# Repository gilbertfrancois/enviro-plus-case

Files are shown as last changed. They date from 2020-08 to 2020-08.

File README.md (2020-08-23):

# Enviro+ and PMS5003 case

## About

*Designed for environmental monitoring, Enviro+ for Raspberry Pi lets you measure air quality (pollutant gases and particulates), temperature, pressure, humidity, light, and noise level. When combined with a particulate matter sensor, it's great for monitoring air quality just outside your house (more information below), or without the particulate sensor you can use it to monitor indoor conditions.*[1]

- BME280 temperature, pressure, humidity sensor ([datasheet](https://ae-bst.resource.bosch.com/media/_tech/media/datasheets/BST-BME280-DS002.pdf))
- LTR-559 light and proximity sensor ([datasheet](references/ltr-559als-01_ds_v1.pdf))
- MICS6814 analog gas sensor ([datasheet](references/1143_Datasheet-MiCS-6814-rev-8.pdf))
- ADS1015 analog to digital converter (ADC) ([datasheet](references/ads1015.pdf))
- MEMS microphone ([datasheet](references/SPH0645LM4H-B.pdf))
- 0.96" colour LCD (160x80)
- PMS5003 particulate matter sensor

The sensors on the Enviro+ are very sensitive. The default design, where the sensor board is placed directly above the Raspberry Pi (Zero) is not great. The heat coming from the CPU of the RPi has a big influence on the BME280 temperature sensor. To overcome this, I designed a frame for mounting the Raspberry Pi Zero, the Enviro+ and the PMS5003, where the GPIO pins are connected with a ribbon cable.

| CAD | Photo |
| --- | --- |
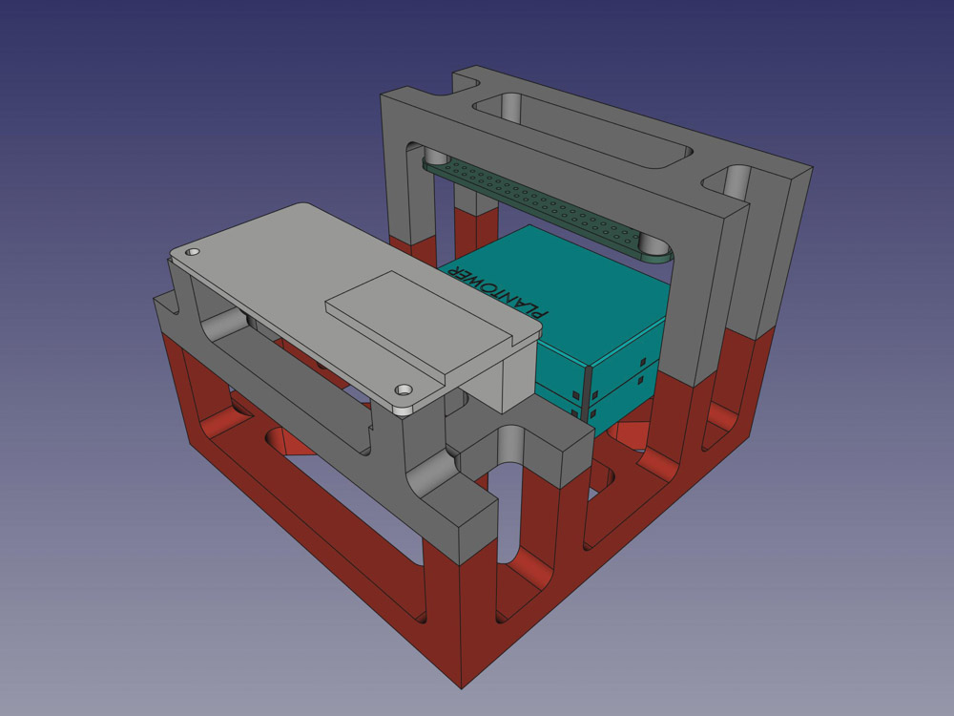
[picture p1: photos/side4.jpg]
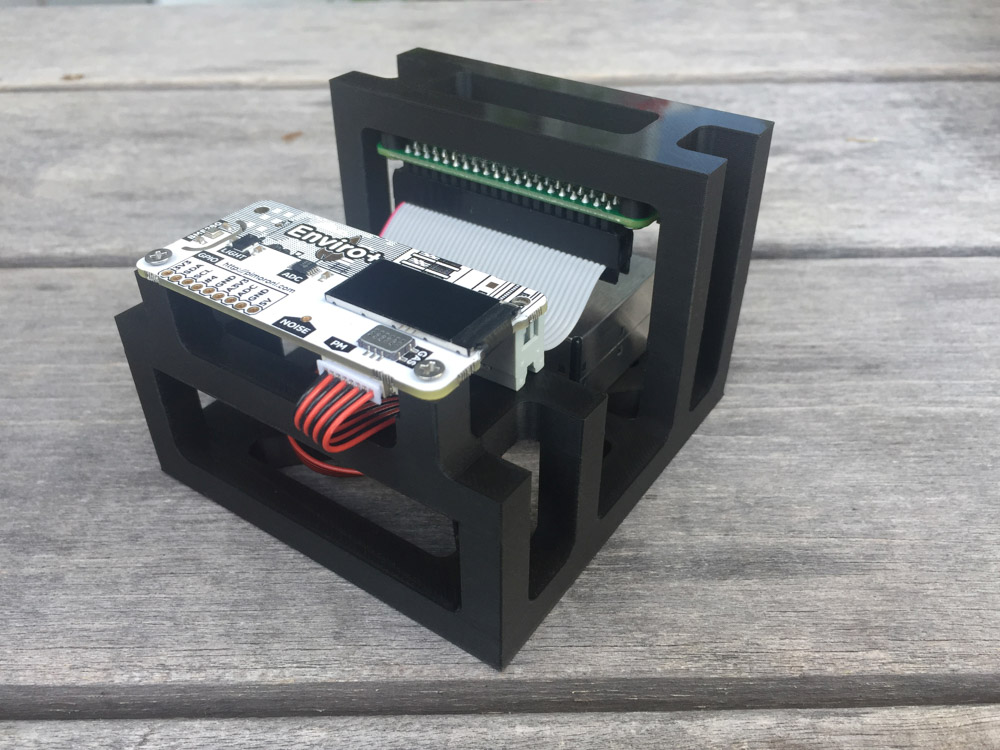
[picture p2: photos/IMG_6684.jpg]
|  |  |
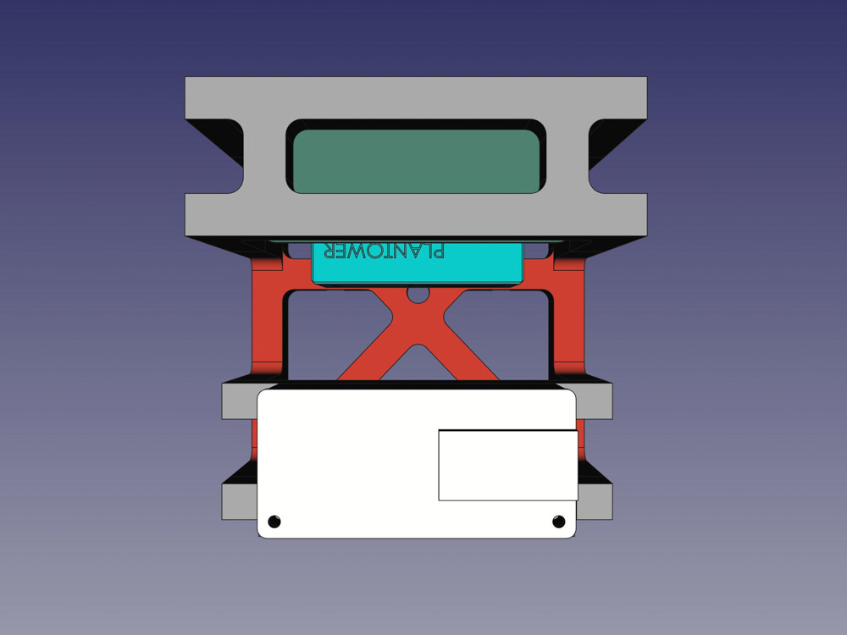
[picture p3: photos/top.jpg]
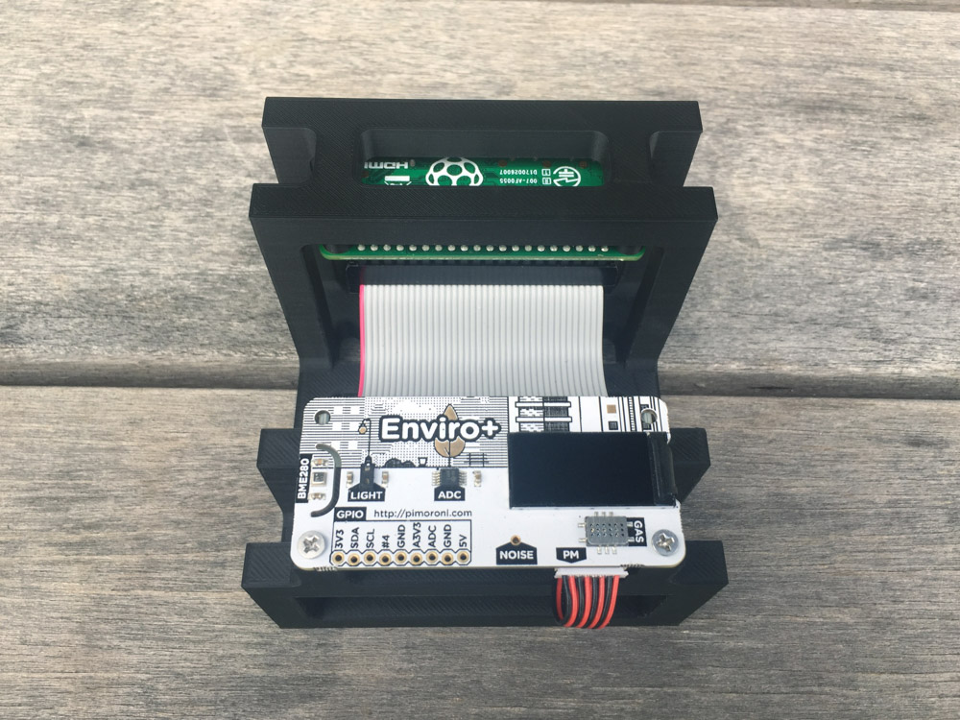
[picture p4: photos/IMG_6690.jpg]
|  |  |
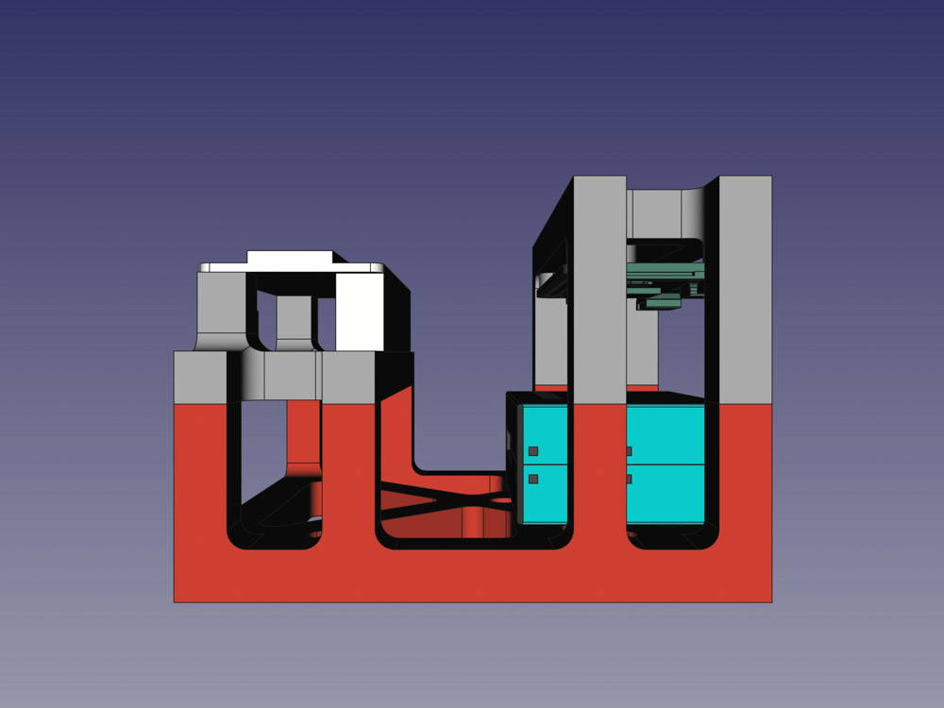
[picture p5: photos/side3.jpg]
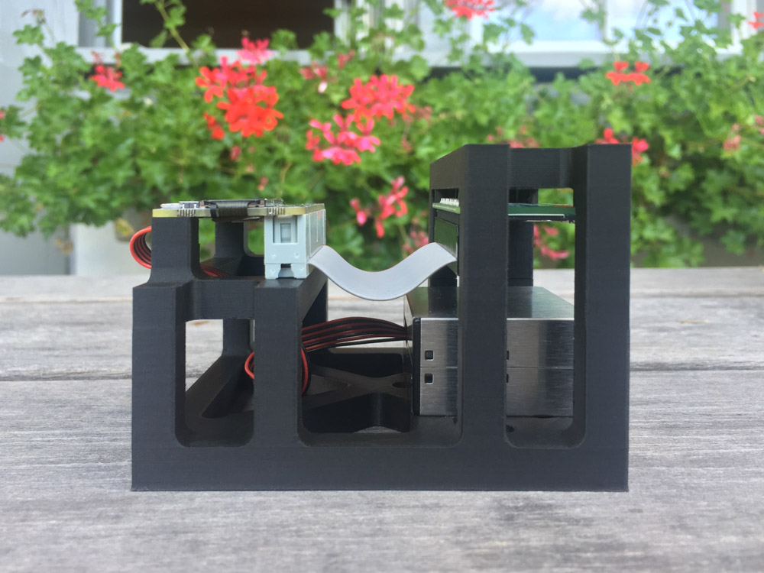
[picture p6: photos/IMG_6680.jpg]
|  |  |
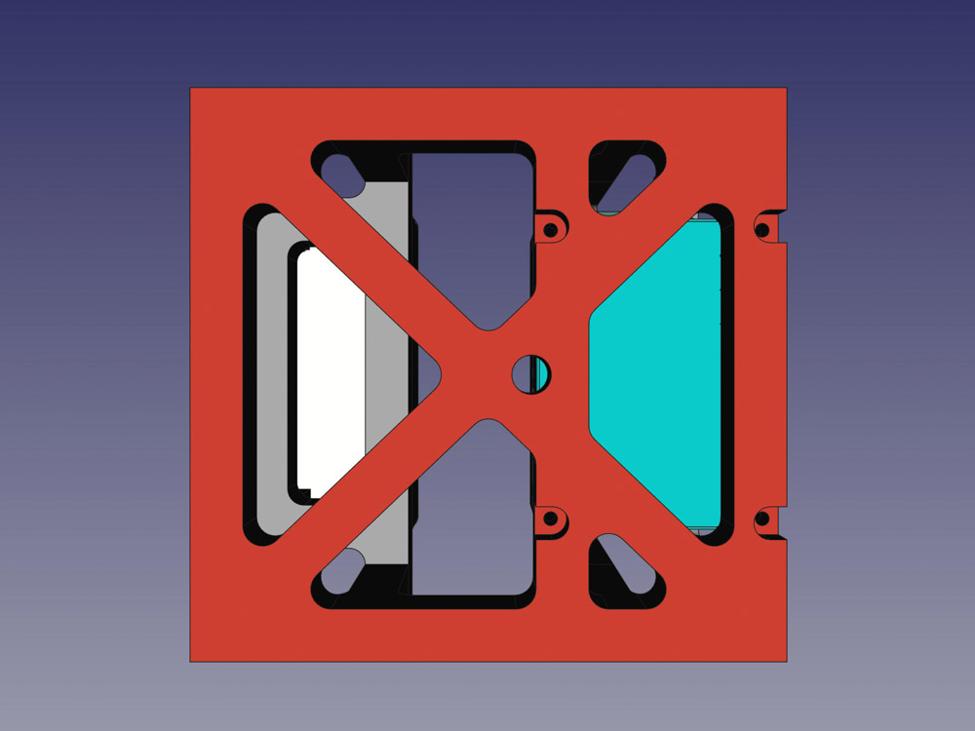
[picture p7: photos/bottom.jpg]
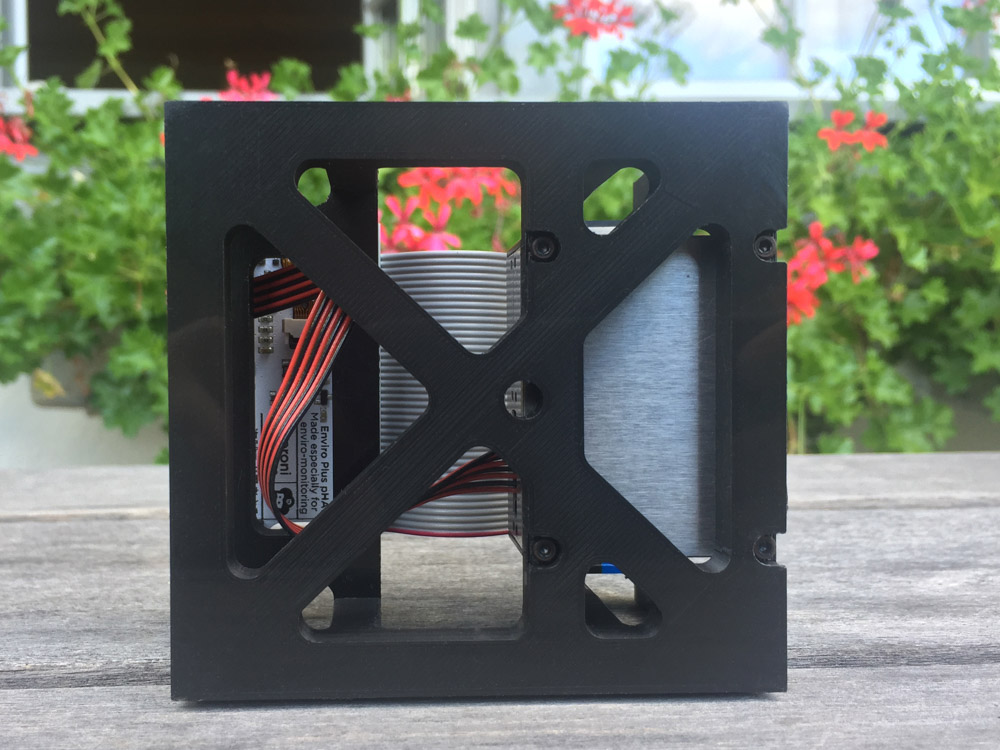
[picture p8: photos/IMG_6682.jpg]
|  |  |

## Print settings

| Setting | Value |
| --- | --- |
| Support | No |
|  Raft | No|
| Vertical resolution | 0.1mm |
| Filament brand | ColorFabb |
| Material | PLA/PHA |
| Infill | 20% |

## Assembly

1 x **Ribbon cable Male - Female**, to connect the Enviro+ to the Raspberry Pi Zero.

4 x **M2 4mm,** to attach the PMS5003 to the frame.

8 x **M2.5 4mm**, to attach the Raspberry Pi and Enviro+ board to the frame.

## References

- [Enviro for Raspberry Pi – Enviro + Air Quality](https://shop.pimoroni.com/products/enviro?variant=31155658457171)
- ["Getting started with Enviro+"](https://learn.pimoroni.com/tutorial/sandyj/getting-started-with-enviro-plus)
- [Review of Pimoroni's Enviro+ board - Part1: gas, temp., humidity, pressure and particulate matter](https://www.youtube.com/watch?v=L1kl1kVbmBw)
- [Review of Pimoroni's Enviro+ board - Part2: LCD, noise level, light+proximity](https://www.youtube.com/watch?v=d4MCVbEHTlE)

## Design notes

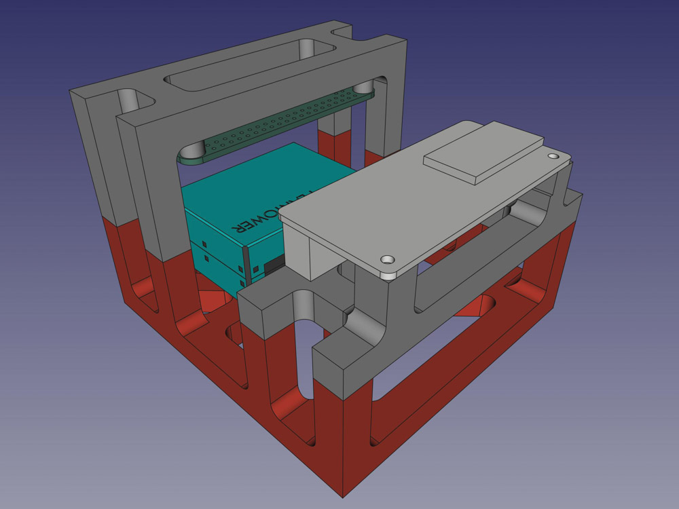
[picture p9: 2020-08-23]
photos/side2.jpg

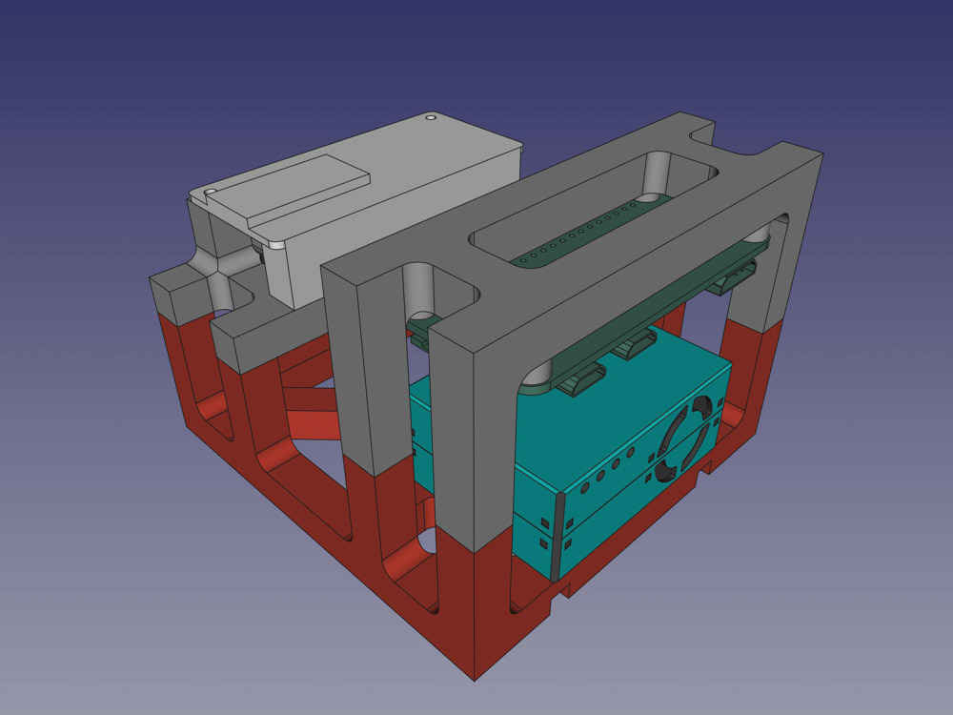
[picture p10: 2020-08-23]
photos/side1.jpg

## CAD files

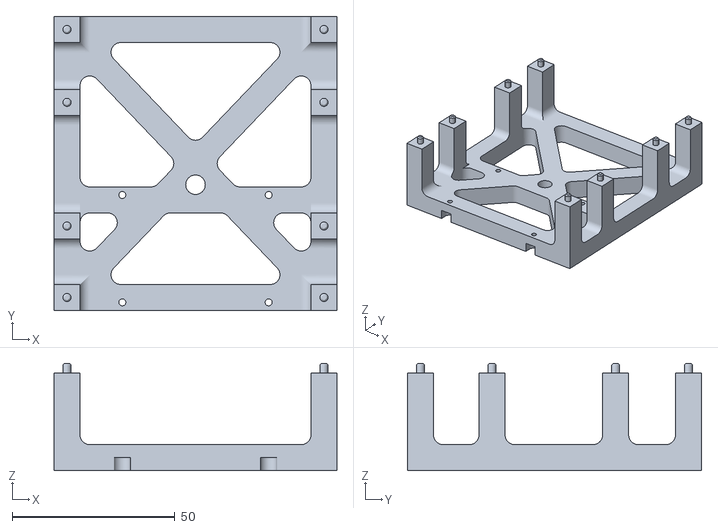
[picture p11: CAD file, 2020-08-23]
stl/bottom rig.stl
87.0 x 90.4 x 33.0

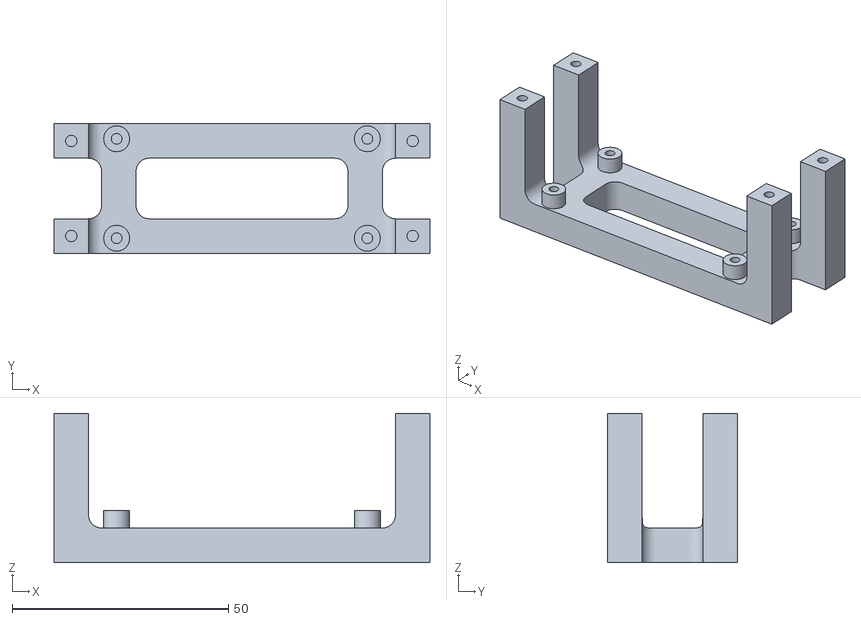
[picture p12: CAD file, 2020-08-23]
stl/rpi bench.stl
87.0 x 30.0 x 34.5

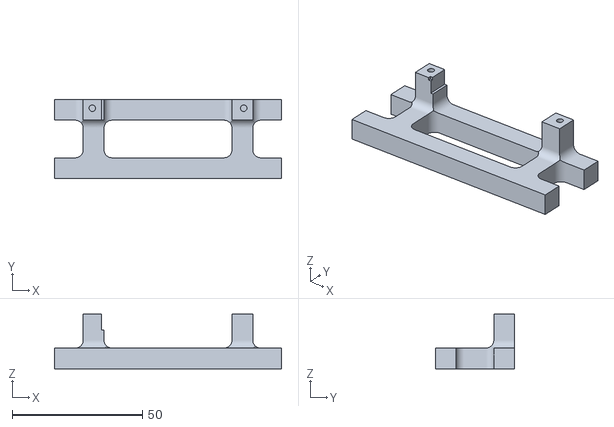
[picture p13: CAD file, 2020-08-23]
stl/sensor bench.stl
87.0 x 30.4 x 21.0

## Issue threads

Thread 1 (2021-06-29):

Ribbon cable source

tvigers, 2021-06-29:
Hi,

Was just wondering where you were able to source a ribbon cable like that?

I've searched around a little bit but have been unable to find one that short/have a perfect angle like that?

Cheers,

Tim

gilbertfrancois, 2021-06-29:
I modified the cable myself. It is a standard male to female 40pins IDE harddisk ribbon cable. I carefully opened the grey male plug and placed it at the desired position. Then I've cut the ribbon cable to its new length.

Closed 2021-06-29.
